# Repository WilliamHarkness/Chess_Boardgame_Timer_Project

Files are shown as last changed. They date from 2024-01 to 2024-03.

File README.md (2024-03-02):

# Chess Clock

This repository contains a simple Chess Clock application implemented in Arduino IDE language (C? / C++?)

## Features

- Poker mode including hand counter, timer and individual player timer.
- Up counting mode. 1-9 players (for other timing purposes). 
- Down counting mode. 1-9 players (for other timing purposes). Includes time back, and individual time custimization
- Buzzer 
- Loop mode 1-9 players. Loops timer. Good for turn timer. Resets to default on button press
-Battery opperated

## Blender file for 3d printing

- This file is what was used for the 3d printing

## KiCAN file for PCB

- Main board and Display board for each display
- Used jlbPCB for printing. Was pretty useful. 

## Partlist 

## Partlist 

| Component | Part Number/Description |
|---|---|
| ATMEGA | ATMEGA32 |
| Control SW | SW-PB1-1DZ-A-P1-A |
| Multiplexer | CD4028BM96 |
| Buzzer | WST-1210T |
| Battery Holder | 36-234-ND |
| 5v Switching Reg | AP63205QWU-7 |
| Inductor | B78108E1472K000 |
| Caps 100nF 0603 | |
| Caps 22uF 0603 | |
| Main Button (Amazon) | DaierTek 6pcs 12V Momentary Push Button Switch 12mm Waterproof Small Round Mini Micro Black Metal Power Pushbutton SPST for Car RV Marine Boat Automotive |
| Power Button (Amazon)  | QTEATAK 5Pcs On/Off Boat Rocker Switch 5Pcs 2 Pin 2 Position Snap 12V 110V 250V |
| Player Button | 12Pcs Arcade Joystick Game Console Buttons 30mm Replacement Button for Most Hori and for MadCatz, Snap in Installation |

## ETC

I may be missing some parts from the list. I got most on digikey and the rest on amazon.
This design should be simplified But was sucessful for my purposes.

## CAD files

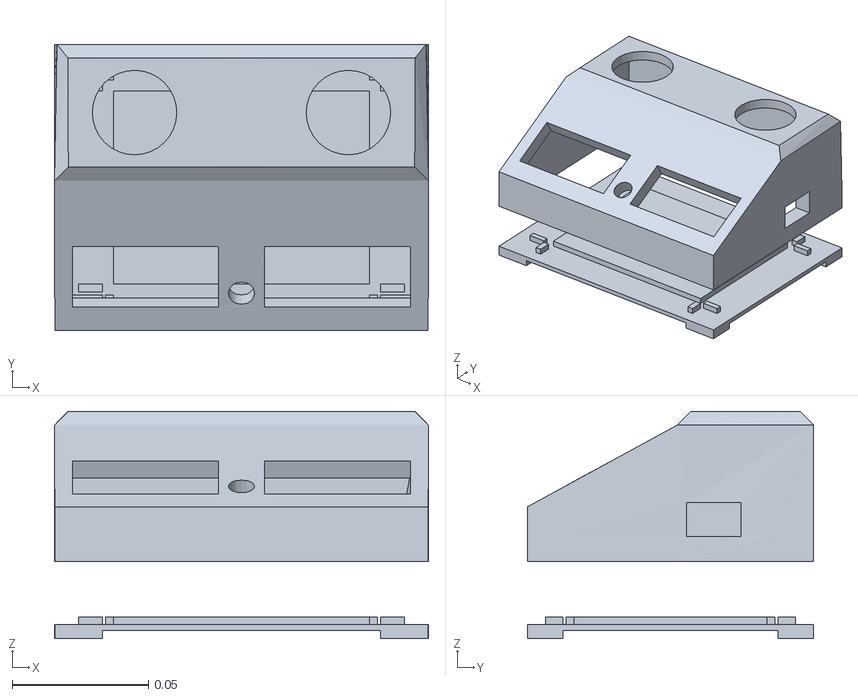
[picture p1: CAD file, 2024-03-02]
KiCAN/LED_PROJECT/ChessClockV1.stl
0.137 x 0.105 x 0.0835

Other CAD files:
Blender/ChessClockV1.blend

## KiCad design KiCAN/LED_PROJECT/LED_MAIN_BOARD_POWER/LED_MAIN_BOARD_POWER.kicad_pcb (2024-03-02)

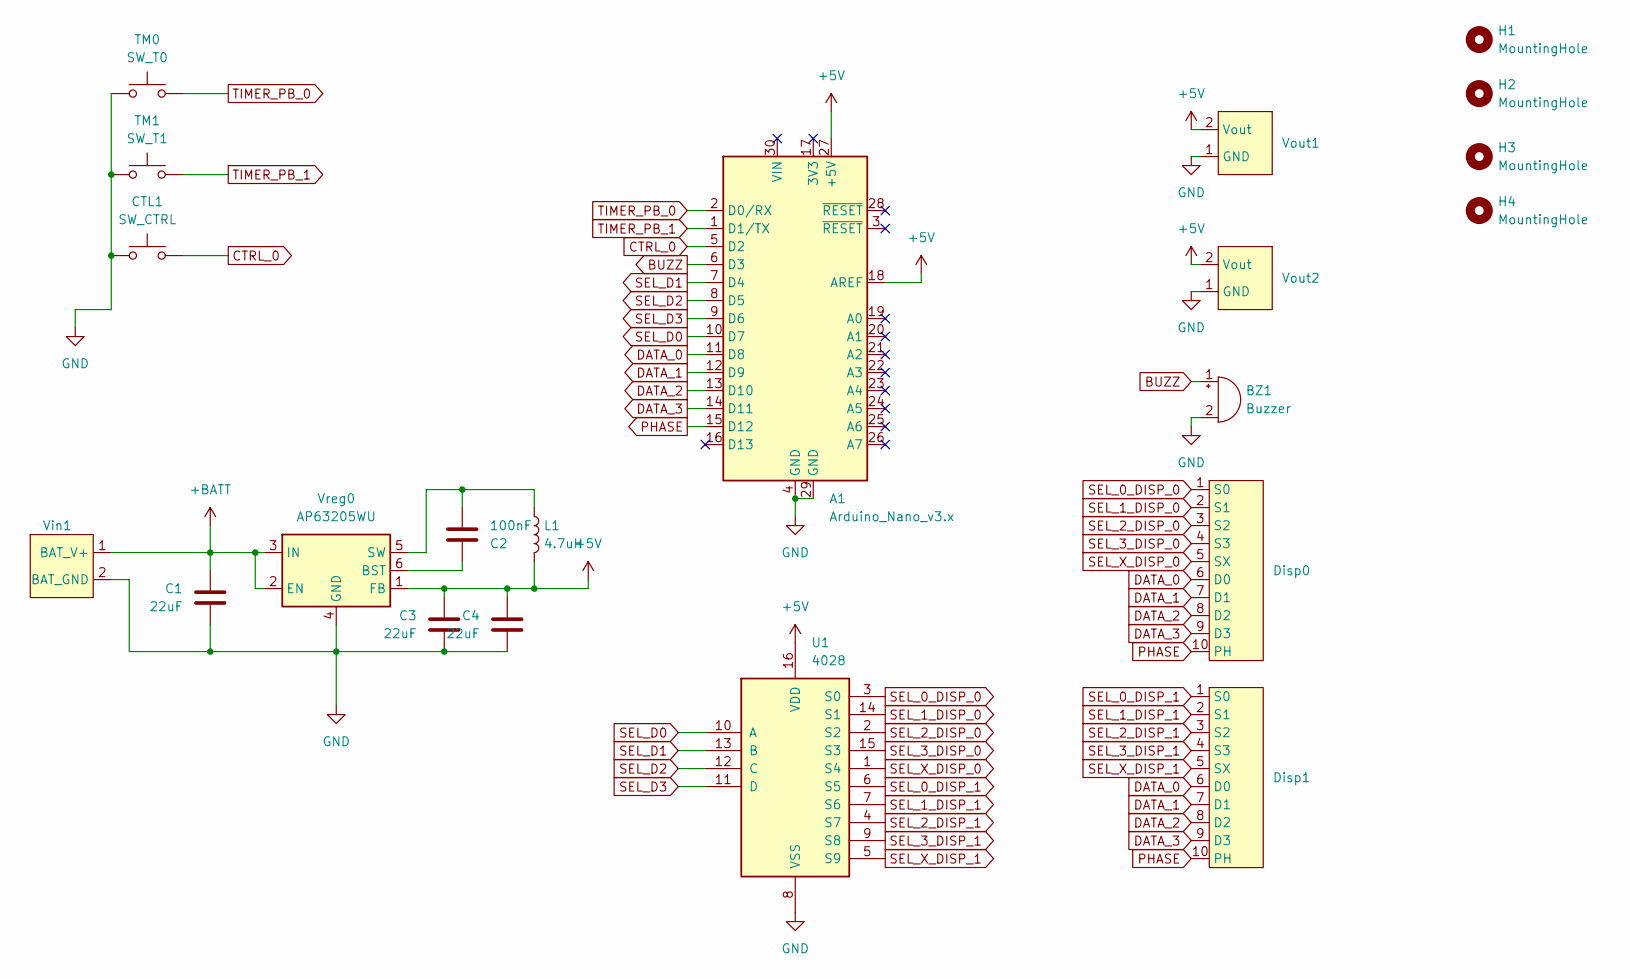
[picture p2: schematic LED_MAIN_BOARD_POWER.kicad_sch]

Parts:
A1: Arduino_Nano_v3.x; Arduino_Nano
BZ1: Buzzer; Buzzer_12x9.5RM7.6
C1, C3, C4: 22uF; C_0603_1608Metric_Pad1.08x0.95mm_HandSolder
C2: 100nF; C_0603_1608Metric_Pad1.08x0.95mm_HandSolder
CTL1: SW_CTRL; 2-Pad_FP
Disp0, Disp1: 10-Pad-OP
H1, H2, H3, H4: MountingHole; MountingHole_3.2mm_M3
L1: 4.7uH; R_Axial_DIN0207_L6.3mm_D2.5mm_P10.16mm_Horizontal
TM0: SW_T0; 2-Pad_FP
TM1: SW_T1; 2-Pad_FP
U1: 4028; SOIC-16_3.9x9.9mm_P1.27mm
Vin1: 2-Pad_FP
Vout1, Vout2: 2-Pad_FP
Vreg0: AP63205WU; TSOT-23-6_HandSoldering

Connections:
+5V: A1.18 (AREF), A1.27 (+5V), C3.1, C4.1, L1.2, U1.16 (VDD), Vout1.2 (Vout), Vout2.2 (Vout), Vreg0.1 (FB)
+BATT: C1.1, Vin1.1 (BAT_V+), Vreg0.2 (EN), Vreg0.3 (IN)
BUZZ: A1.6 (D3), BZ1.1 (-)
CTRL_0: A1.5 (D2), CTL1.2
DATA_0: A1.11 (D8), Disp0.6 (D0), Disp1.6 (D0)
DATA_1: A1.12 (D9), Disp0.7 (D1), Disp1.7 (D1)
DATA_2: A1.13 (D10), Disp0.8 (D2), Disp1.8 (D2)
DATA_3: A1.14 (D11), Disp0.9 (D3), Disp1.9 (D3)
GND: A1.4 (GND), A1.29 (GND), BZ1.2 (+), C1.2, C3.2, C4.2, CTL1.1, TM0.1, TM1.1, U1.8 (VSS), Vin1.2 (BAT_GND), Vout1.1 (GND), Vout2.1 (GND), Vreg0.4 (GND)
unnamed: C2.1, Vreg0.6 (BST)
unnamed: C2.2, L1.1, Vreg0.5 (SW)
PHASE: A1.15 (D12), Disp0.10 (PH), Disp1.10 (PH)
SEL_0_DISP_0: Disp0.1 (S0), U1.3 (S0)
SEL_0_DISP_1: Disp1.1 (S0), U1.6 (S5)
SEL_1_DISP_0: Disp0.2 (S1), U1.14 (S1)
SEL_1_DISP_1: Disp1.2 (S1), U1.7 (S6)
SEL_2_DISP_0: Disp0.3 (S2), U1.2 (S2)
SEL_2_DISP_1: Disp1.3 (S2), U1.4 (S7)
SEL_3_DISP_0: Disp0.4 (S3), U1.15 (S3)
SEL_3_DISP_1: Disp1.4 (S3), U1.9 (S8)
SEL_D0: A1.10 (D7), U1.10 (A)
SEL_D1: A1.7 (D4), U1.13 (B)
SEL_D2: A1.8 (D5), U1.12 (C)
SEL_D3: A1.9 (D6), U1.11 (D)
SEL_X_DISP_0: Disp0.5 (SX), U1.1 (S4)
SEL_X_DISP_1: Disp1.5 (SX), U1.5 (S9)
TIMER_PB_0: A1.2 (D0/RX), TM0.2
TIMER_PB_1: A1.1 (D1/TX), TM1.2

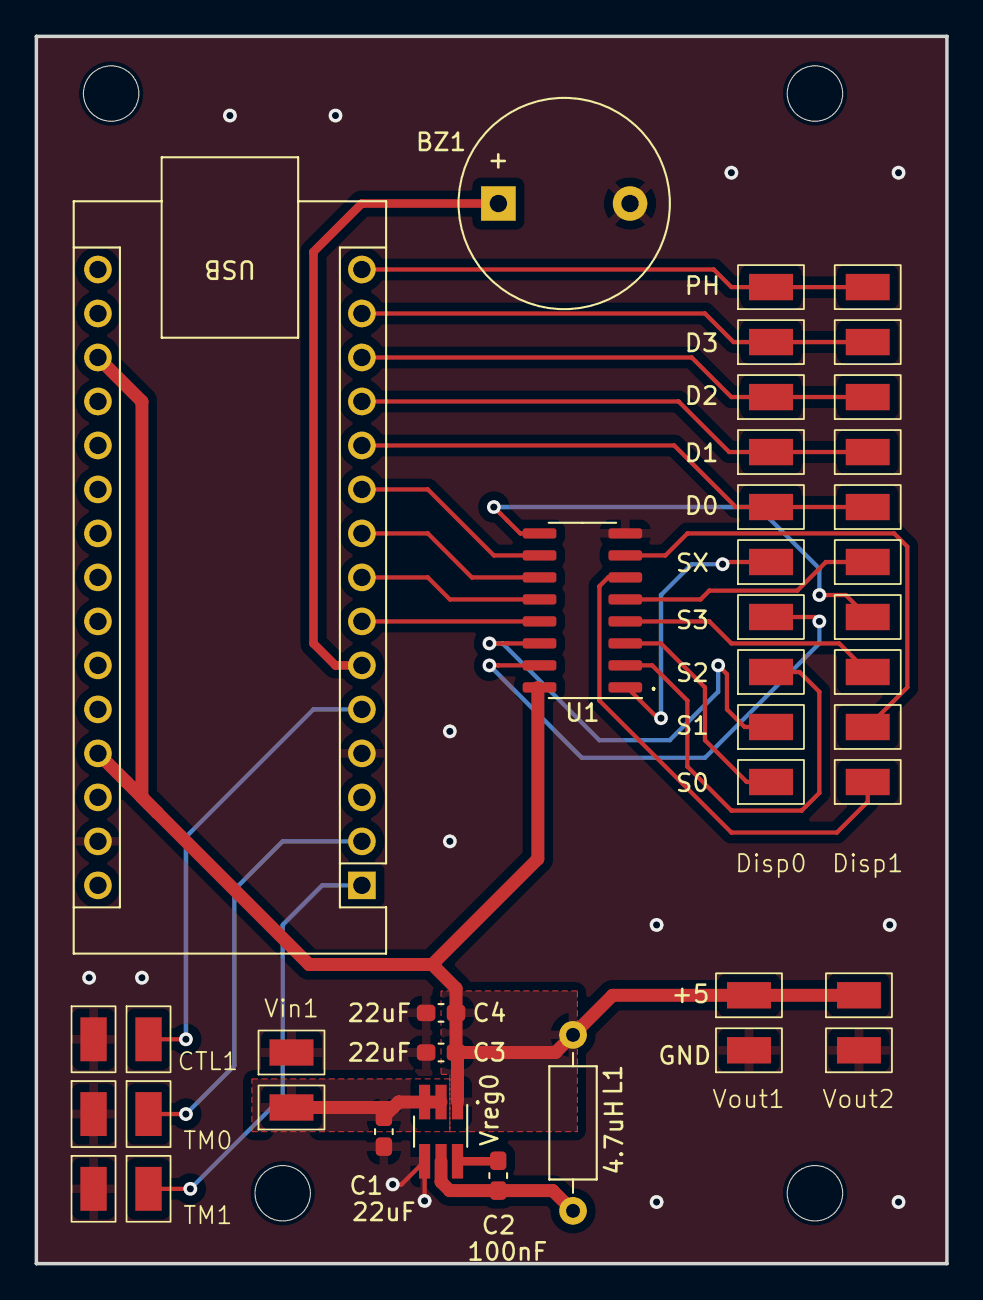
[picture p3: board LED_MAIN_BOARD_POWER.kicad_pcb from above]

Board: 2 copper layers, 52.6 x 70.9 mm, 21 parts (0 on the bottom side), 28 nets.

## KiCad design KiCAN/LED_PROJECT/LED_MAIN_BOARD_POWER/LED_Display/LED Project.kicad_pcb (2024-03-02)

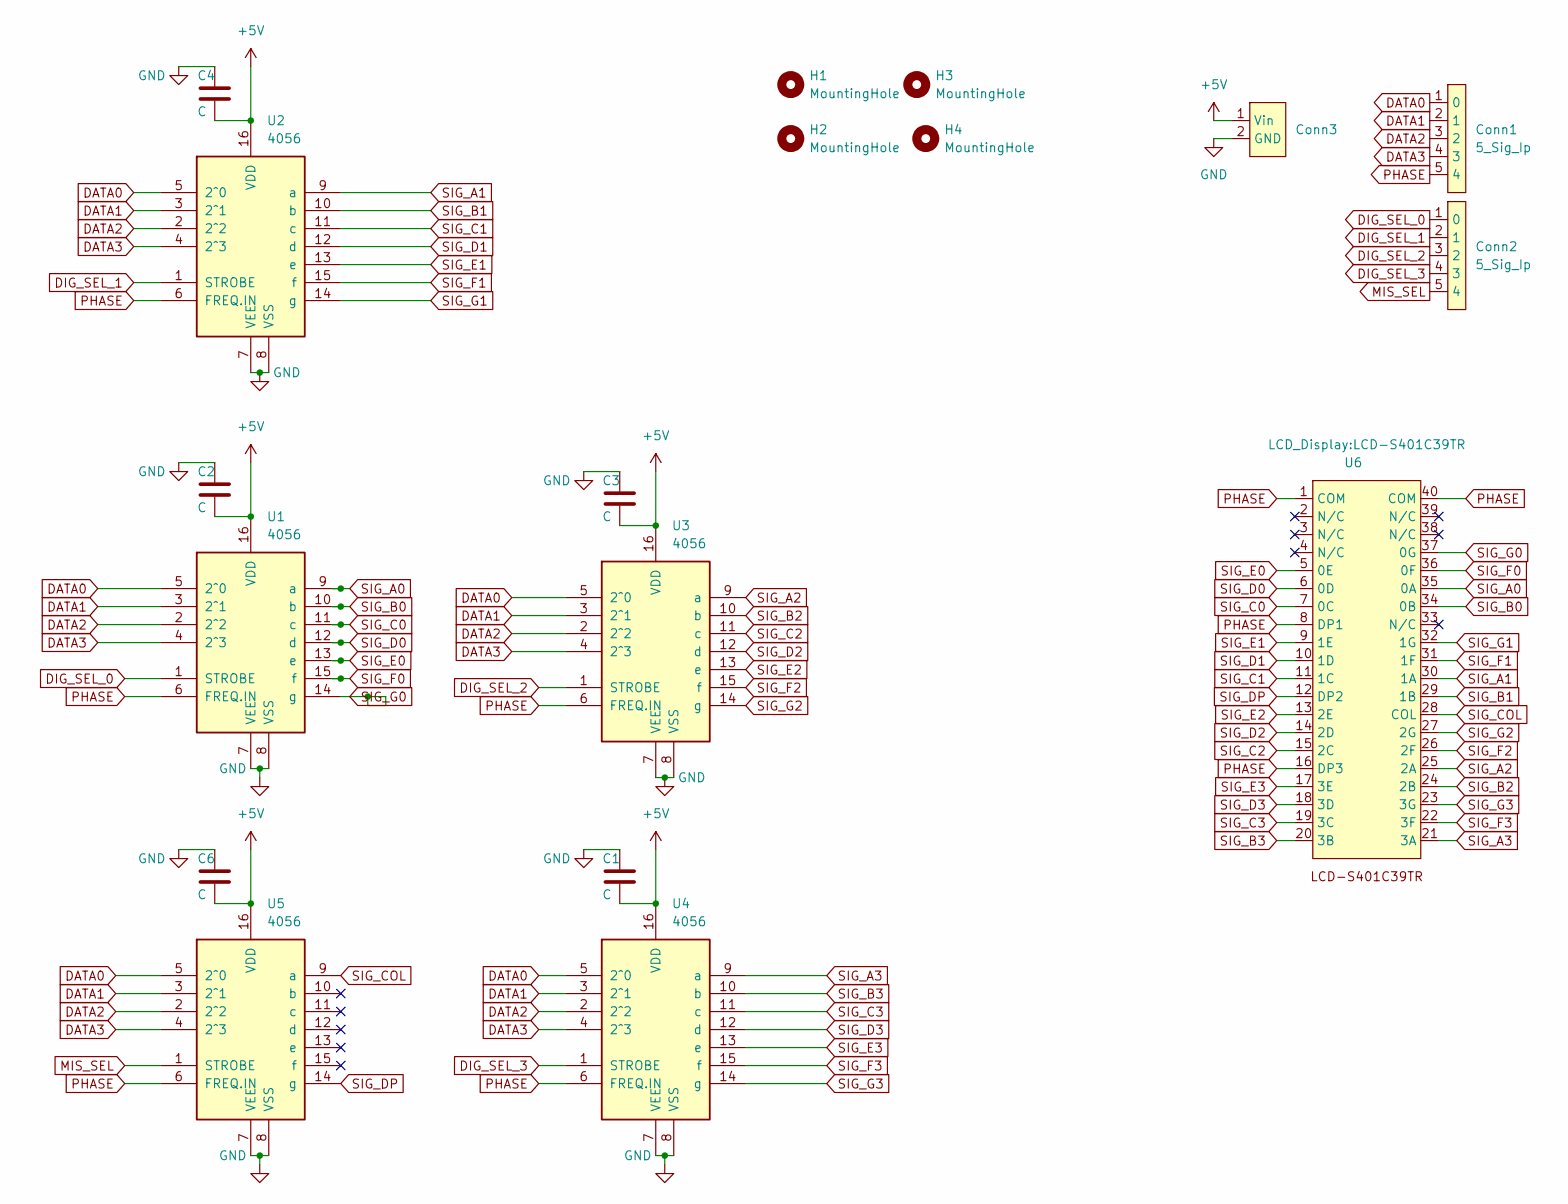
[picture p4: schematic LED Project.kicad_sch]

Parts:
C1, C2, C3, C4, C6: C; C_0603_1608Metric
Conn1, Conn2: 5_Sig_Ip; PAD_5
Conn3: PAD_2
H1, H2, H3, H4: MountingHole; MountingHole_2.2mm_M2
U1, U2, U3, U4, U5: 4056; SOIC-16_3.9x9.9mm_P1.27mm
U6: LCD-S401C39TR

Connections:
+5V: C1.2, C2.2, C3.2, C4.2, C6.2, Conn3.1 (Vin), U1.16 (VDD), U2.16 (VDD), U3.16 (VDD), U4.16 (VDD), U5.16 (VDD)
DATA0: Conn1.1 (0), U1.5 (2^0), U2.5 (2^0), U3.5 (2^0), U4.5 (2^0), U5.5 (2^0)
DATA1: Conn1.2 (1), U1.3 (2^1), U2.3 (2^1), U3.3 (2^1), U4.3 (2^1), U5.3 (2^1)
DATA2: Conn1.3 (2), U1.2 (2^2), U2.2 (2^2), U3.2 (2^2), U4.2 (2^2), U5.2 (2^2)
DATA3: Conn1.4 (3), U1.4 (2^3), U2.4 (2^3), U3.4 (2^3), U4.4 (2^3), U5.4 (2^3)
DIG_SEL_0: Conn2.1 (0), U1.1 (STROBE)
DIG_SEL_1: Conn2.2 (1), U2.1 (STROBE)
DIG_SEL_2: Conn2.3 (2), U3.1 (STROBE)
DIG_SEL_3: Conn2.4 (3), U4.1 (STROBE)
GND: C1.1, C2.1, C3.1, C4.1, C6.1, Conn3.2 (GND), U1.7 (VEE), U1.8 (VSS), U2.7 (VEE), U2.8 (VSS), U3.7 (VEE), U3.8 (VSS), U4.7 (VEE), U4.8 (VSS), U5.7 (VEE), U5.8 (VSS)
MIS_SEL: Conn2.5 (4), U5.1 (STROBE)
PHASE: Conn1.5 (4), U1.6 (FREQ.IN), U2.6 (FREQ.IN), U3.6 (FREQ.IN), U4.6 (FREQ.IN), U5.6 (FREQ.IN), U6.1 (COM), U6.8 (DP1), U6.16 (DP3), U6.40 (COM)
SIG_A0: U1.9 (a), U6.35 (0A)
SIG_A1: U2.9 (a), U6.30 (1A)
SIG_A2: U3.9 (a), U6.25 (2A)
SIG_A3: U4.9 (a), U6.21 (3A)
SIG_B0: U1.10 (b), U6.34 (0B)
SIG_B1: U2.10 (b), U6.29 (1B)
SIG_B2: U3.10 (b), U6.24 (2B)
SIG_B3: U4.10 (b), U6.20 (3B)
SIG_C0: U1.11 (c), U6.7 (0C)
SIG_C1: U2.11 (c), U6.11 (1C)
SIG_C2: U3.11 (c), U6.15 (2C)
SIG_C3: U4.11 (c), U6.19 (3C)
SIG_COL: U5.9 (a), U6.28 (COL)
SIG_D0: U1.12 (d), U6.6 (0D)
SIG_D1: U2.12 (d), U6.10 (1D)
SIG_D2: U3.12 (d), U6.14 (2D)
SIG_D3: U4.12 (d), U6.18 (3D)
SIG_DP: U5.14 (g), U6.12 (DP2)
SIG_E0: U1.13 (e), U6.5 (0E)
SIG_E1: U2.13 (e), U6.9 (1E)
SIG_E2: U3.13 (e), U6.13 (2E)
SIG_E3: U4.13 (e), U6.17 (3E)
SIG_F0: U1.15 (f), U6.36 (0F)
SIG_F1: U2.15 (f), U6.31 (1F)
SIG_F2: U3.15 (f), U6.26 (2F)
SIG_F3: U4.15 (f), U6.22 (3F)
SIG_G0: U1.14 (g), U6.37 (0G)
SIG_G1: U2.14 (g), U6.32 (1G)
SIG_G2: U3.14 (g), U6.27 (2G)
SIG_G3: U4.14 (g), U6.23 (3G)

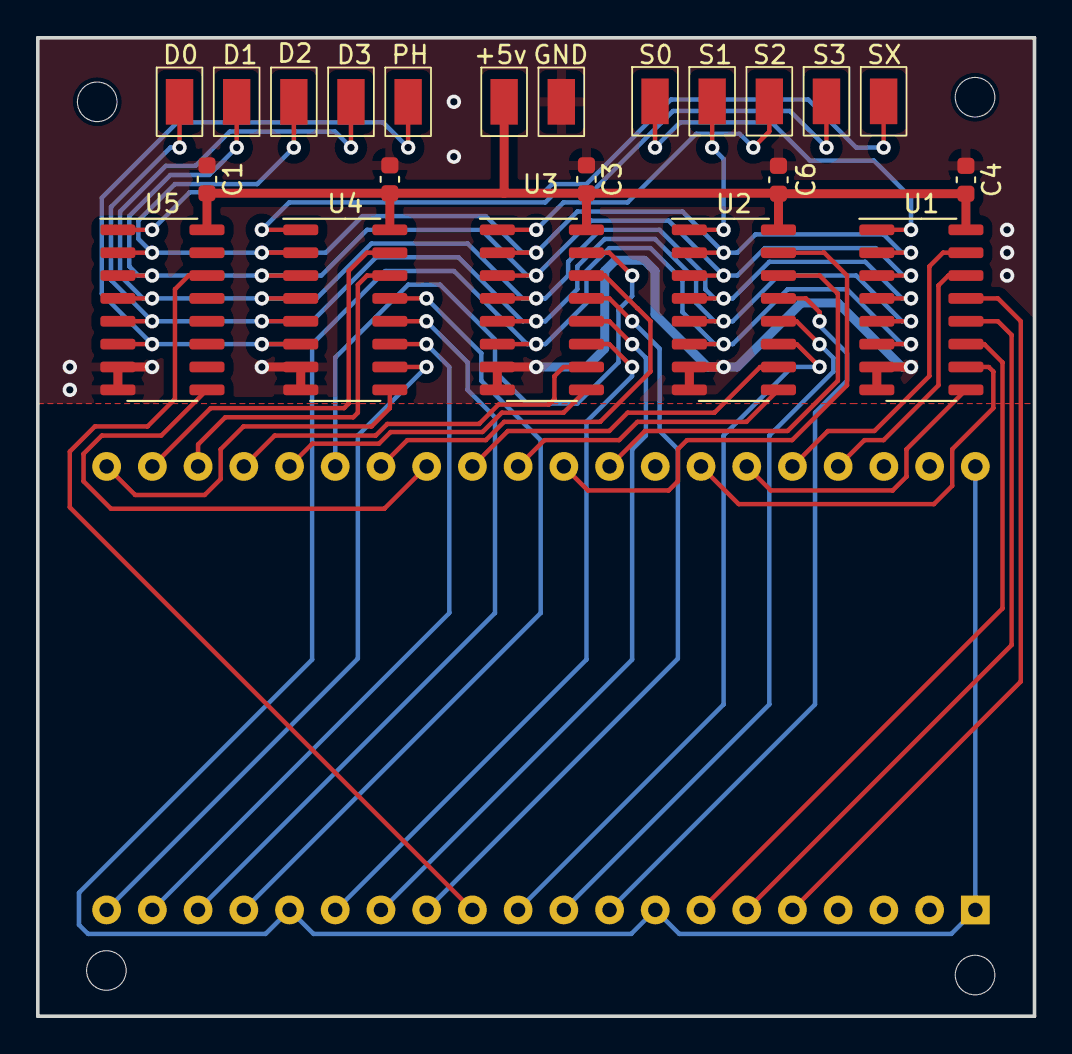
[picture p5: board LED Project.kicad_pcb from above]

Board: 2 copper layers, 55.4 x 54.4 mm, 18 parts (1 on the bottom side), 42 nets.

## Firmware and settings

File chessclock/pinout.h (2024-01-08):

#ifndef __PINNOUT_H__
#define __PINNOUT_H__

#define TIMER0_PIN 0U
#define TIMER1_PIN 1U
#define CTRL_PIN 2U

#define BUZZER_PIN 3U

#define SEL0_PIN 7U
#define SEL1_PIN 4U
#define SEL2_PIN 5U
#define SEL3_PIN 6U

#define DATA0_PIN 8U
#define DATA1_PIN 9U
#define DATA2_PIN 10U
#define DATA3_PIN 11U

#define PHASE_PIN 12U

#endif /* __PINNOUT_H__ */

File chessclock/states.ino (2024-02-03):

#include "processes.h"

///////////////// LOCAL FUNCTIONS ///////////////////////

stateStatus_t defaultProcess(gameState_t* state, stateStatus_t stateStatus){
    if(state == NULL){
        return STATE_ERROR;
    }

    return STATE_RUNNING;
}

///////////////// GLOBAL DEFINITIONS ////////////////////

static gameState_t* g_currentState = NULL;
static stateStatus_t g_status = STATE_START; 

extern gameState_t g_splashScreenState;

//////////////// App Interface ///////////////////////

stateStatus_t initState(void){
    g_currentState = &g_splashScreenState;
    g_status = STATE_START;
}

stateStatus_t processState(void){
    if(g_currentState == NULL){
        g_status = STATE_ERROR;
    }
    if(g_status != STATE_ERROR){
        g_status = g_currentState->m_process(g_currentState, g_status);
        if(STATE_EXIT == g_status){
            if(g_currentState->m_next != NULL){
                if(g_currentState->m_next != g_currentState->m_prev){
                    g_currentState->m_next->m_prev = g_currentState;
                }                
            }
            g_currentState = g_currentState->m_next;
            g_status = STATE_START;
        }
    }
    return g_status;
}

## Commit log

2024-01-08 Better timer interface
2024-02-03 Verson 1.0.0
    Updated clock will complete features
    Probably some bugs still.
    Not "clean" but done quickly and functional
    [blinkTimer.ino, buzzer.ino, display.ino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]
2024-03-02 Updated.
    Added final changes,
    Added Blender Files
    Added KiCAD filesX
    [ChessClockV1.blend, ChessClockV1.stl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]
